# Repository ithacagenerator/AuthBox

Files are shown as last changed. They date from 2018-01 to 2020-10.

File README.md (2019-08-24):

# AuthBox

Some background on where this idea came from in this discussion thread: https://discuss.ithacagenerator.org/t/makerspace-authbox-on-github/565/8

System Diagram

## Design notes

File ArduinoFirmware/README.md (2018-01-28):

***Arduino Libraries***
- https://github.com/Chris--A/Keypad

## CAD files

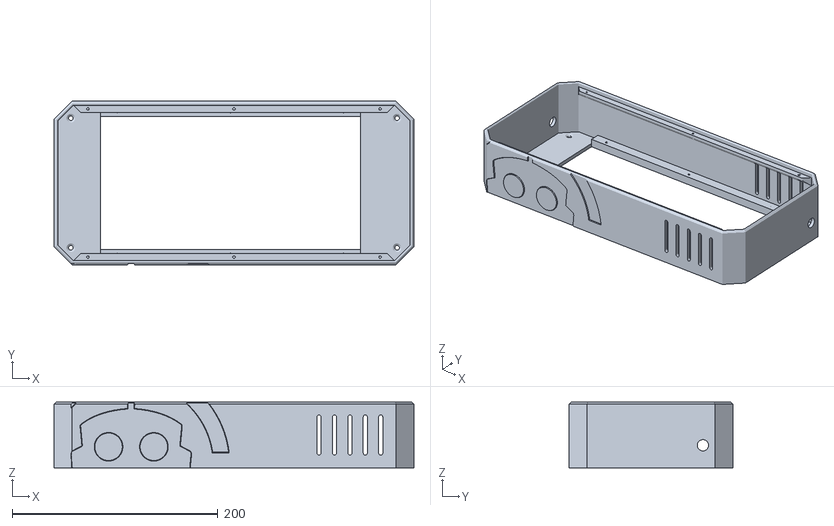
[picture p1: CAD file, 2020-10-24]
Mechanical/authbox_panel.stl
350.0 x 159.0 x 64.0

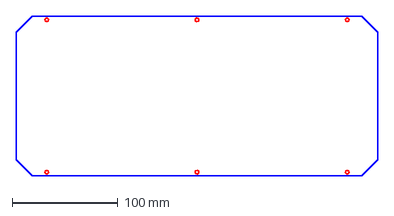
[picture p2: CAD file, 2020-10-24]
Mechanical/top_panel.dxf
341.6 x 150.5 mm

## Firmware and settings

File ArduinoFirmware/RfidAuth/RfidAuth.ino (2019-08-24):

#include <stdlib.h>
#include <stdint.h>
#include <string.h>

// Slight adapatation of Wiegand demo code 
// referenced / linked at http://wiki.seeed.cc/Grove-125KHz_RFID_Reader/
//
// wiring instructions
// RED = 5V from Arduino
// BLACK = GND from Arduino
// WHITE = DIG2 on Arduino
// YELLOW = DIG3 on Arduino
//
// outputs the laser etched code from the RFID reader (sans leading zeroes)
// as an ASCII string, one character at a tim// 
// separated by \r\n 

byte RFIDcardNum[4];
byte evenBit = 0;
byte oddBit = 0;
byte isData0Low = 0;
byte isData1Low = 0;
int recvBitCount = 0;
byte isCardReadOver = 0;

void handleCommands(char c);
uint16_t crc16_update(uint16_t crc, uint8_t a);
uint16_t crc16(char * str, uint8_t len);
uint8_t check_crc16(char * str);
void handleAuthorizeCommand(void);
void handleLockoutCommand(void);
void handleBuzzerOnCommand(void);
void handleBuzzerOffCommand(void);
void enableCounter(void);
void disableCounter(void);

int LOCKOUT_PIN = 13; // Relay control output

// THESE NEED CONFIGURED BASED ON RELAY HARDWARE
int LOCKOUT_PIN_ACTIVE = 1;
int LOCKOUT_PIN_INACTIVE = 1 - LOCKOUT_PIN_ACTIVE;
int INACTIVE_IS_HIGHZ = 1; // means drive Z instead when INACTIVE

int BUZZER_HIGH_PIN = 10;
int BUZZER_LOW_PIN = 9;
boolean buzzer_enabled = false;
boolean buzzer_on = false;
uint32_t previousBuzzerMillis = 0;
const int32_t buzzerInterval = 500; // sets the buzzer beeping frequency

void setup(){
  handleLockoutCommand();
  Serial.begin(9600);
  // Serial.println("Hello RfidAuth");

  attachInterrupt(0, ISRreceiveData0, FALLING );  //data0/tx is connected to pin 2, which results in INT 0
  attachInterrupt(1, ISRreceiveData1, FALLING );  //data1/rx is connected to pin 3, which results in INT 1
  
  pinMode(BUZZER_HIGH_PIN, OUTPUT);
  pinMode(BUZZER_LOW_PIN, OUTPUT);
  digitalWrite(BUZZER_HIGH_PIN, 0); 
  digitalWrite(BUZZER_LOW_PIN, 0);
}

void loop(){
  unsigned long currentMillis = millis();
  if (currentMillis - previousBuzzerMillis >= buzzerInterval) {
    previousBuzzerMillis = currentMillis;

    if(buzzer_enabled){
      if(buzzer_on){
        buzzer_on = false;
        disableCounter();
      }
      else{
        buzzer_on = true;
        enableCounter();        
      }
    }
    else {
      disableCounter();
    }
  }
  
  //read card number bit
  if(isData0Low||isData1Low){
    if(1 == recvBitCount){//even bit
      evenBit = (1-isData0Low)&isData1Low;
    }
    else if( recvBitCount >= 26){//odd bit
      oddBit = (1-isData0Low)&isData1Low;
      isCardReadOver = 1;
      delay(10);
    }
    else{
      //only if isData1Low = 1, card bit could be 1
      RFIDcardNum[2-(recvBitCount-2)/8] |= (isData1Low << (7-(recvBitCount-2)%8));
    }
    //reset data0 and data1
    isData0Low = 0;
    isData1Low = 0;
  }

  if(isCardReadOver){
    if(checkParity()){
      // convert the number to a string
      uint32_t number = *((uint32_t *)RFIDcardNum);
      char tmp[16] = {0};
      sprintf(tmp, "%lu", number);
      uint8_t len = strlen(tmp);
      for(uint8_t ii = 0; ii < len; ii++){
        Serial.println(tmp[ii]);
      }
      Serial.println('#'); // append the 'enter' key
    }
    resetData();
  }

  while (Serial.available()){
      handleCommands(Serial.read());
  }  

}

byte checkParity(){
  int i = 0;
  int evenCount = 0;
  int oddCount = 0;
  for(i = 0; i < 8; i++){
    if(RFIDcardNum[2]&(0x80>>i)){
      evenCount++;
    }
  }
  for(i = 0; i < 4; i++){
    if(RFIDcardNum[1]&(0x80>>i)){
      evenCount++;
    }
  }
  for(i = 4; i < 8; i++){
    if(RFIDcardNum[1]&(0x80>>i)){
      oddCount++;
    }
  }
  for(i = 0; i < 8; i++){
    if(RFIDcardNum[0]&(0x80>>i)){
      oddCount++;
    }
  }
  
  if(evenCount%2 == evenBit && oddCount%2 != oddBit){
    return 1;
  }
  else{
    return 0;
  }
}
void resetData(){
  RFIDcardNum[0] = 0;
  RFIDcardNum[1] = 0;
  RFIDcardNum[2] = 0;
  RFIDcardNum[3] = 0;
  evenBit = 0;
  oddBit = 0;
  recvBitCount = 0;
  isData0Low = 0;
  isData1Low = 0;
  isCardReadOver = 0;
}
// handle interrupt0
void ISRreceiveData0(){
  recvBitCount++;
  isData0Low = 1;
}

// handle interrupt1
void ISRreceiveData1(){
  recvBitCount++;
  isData1Low = 1;
}

uint16_t crc16_update(uint16_t crc, uint8_t a){
    crc ^= a;
    for (uint8_t i = 0; i < 8; ++i){
        if (crc & 1)
            crc = (crc >> 1) ^ 0xA001;
        else
            crc = (crc >> 1);
    }

    return crc;
}

uint16_t crc16(char * str, uint8_t len){
    uint16_t crc = 0;
    for(uint16_t ii = 0; ii < len; ii++){
        crc = crc16_update(crc, str[ii]);
    }
    return crc;
}

uint8_t check_crc16(char * str){
    uint8_t ret = 0;
    uint8_t len = strlen(str);
    if(len >= 5){
        uint16_t calculated_crc16 = crc16(str, len - 4);
        char * temp;        
        uint16_t expected_crc16 = strtol(str + strlen(str) - 4, &temp, 16); // base 16
        if (*temp == NULL){
            if(calculated_crc16 == expected_crc16){
                ret = 1; // success!
            }
        }
    }
    return ret;
}

// state machine for handline incoming characters from the Raspberry Pi
// commands are always terminated by XXXX\n, 
// where XXXX is a CRC16 of the bytes in the command as a HEX-string and \n is a newline character
// CRC16 is computed on the byte values in the line up to the checksum
// CRC16 implementation is explicitly included as a function below
// taking the algorithm from http://www.nongnu.org/avr-libc/user-manual/group__util__crc.html
// this should make it pretty difficult to "accidentally" send an authorization command
// though it's admittedly kind of overkill when the commands are not parametric
// should be relatively easy to extend this command processing logic to support more commands
//
// valid commands are:
//   authorize40A2\n
//   lockoutDF6B\n
//   sirenF012
//   quiet6C9D
void handleCommands(char c){
    static char lineBuffer[64] = {0}; // allow up to 63 characters in a command (plus null terminator)
    static uint8_t idx = 0;
    if(c == '\n' || c == '\r'){
        // newline triggers processing of the command, but only if the checksum is sound
        // remember the last four characters in the buffer are expected to be a hex value string
        if(check_crc16(lineBuffer)){
            lineBuffer[strlen(lineBuffer) - 4] = '\0'; // don't need the checksum anymore
            if(0 == strcmp_P(lineBuffer, PSTR("authorize"))){
                handleAuthorizeCommand();
            }
            else if(0 == strcmp_P(lineBuffer, PSTR("lockout"))){
                handleLockoutCommand();
            }
            else if(0 == strcmp_P(lineBuffer, PSTR("siren"))){
                handleBuzzerOnCommand();
            }
            else if(0 == strcmp_P(lineBuffer, PSTR("quiet"))){
                handleBuzzerOffCommand(); 
            }            
            else {
              Serial.print(F("Unknown Command: \"")); Serial.print(lineBuffer); Serial.print(F("\""));Serial.println();              
            }
        }
        else{
            Serial.print(F("Invalid CRC16: \"")); Serial.print(lineBuffer); Serial.print(F("\""));Serial.println();
        }

        idx = 0; // get ready for next line
        memset(lineBuffer, 0, sizeof(lineBuffer));        
    }
    else{
        // buffer the character
        lineBuffer[idx] = c;

        // advance the write index, the highest value idx should ever hold is
        // 62 for a 64 byte buffer, because 63 must always hold a null terminator
        // if you would overflow, just keep overwriting the last possible buffer entry
        if(idx < (sizeof(lineBuffer) - 1)){
            idx++;
        }
    }
}

void handleAuthorizeCommand(void){    
    Serial.println("authorize");
    pinMode(LOCKOUT_PIN, OUTPUT);
    digitalWrite(LOCKOUT_PIN, LOCKOUT_PIN_ACTIVE);
}

void handleLockoutCommand(void){    
    Serial.println("lockout");   
    if (INACTIVE_IS_HIGHZ) { 
      pinMode(LOCKOUT_PIN, INPUT);
    } else {
      pinMode(LOCKOUT_PIN, OUTPUT);
      digitalWrite(LOCKOUT_PIN, LOCKOUT_PIN_INACTIVE);
    }
}

void handleBuzzerOnCommand(void){
  Serial.println("siren");     
  // set for Phase + Frequency Correct PWM Mode
  // WGM3:0 = 1000
  // IRC1 = TOP   -- determines output frequency = CLK / ( 2 * Prescale * TOP)
  //                 CLK = 16000000 Hz
  //                 Prescale = 1, 8, 64, 256, or 1024
  //                 pick TOP so that output frequency ~ 4000
  // a perfect match is PRESCALER = 8, TOP = 250 ... 16MHz / (2 * 8 * 250) = 1000kHz / 250 = 4kHz
  //
  // COM1A1:0 = 10 set/clear
  // COM1B1:0 = 11 clear/set
  // Set ORC1A = ORCR1B to 1/2 IRCR = 125

  if(!buzzer_enabled){
    OCR1A  = 125;
    OCR1B  = 125;
    ICR1   = 250;
    TCCR1A = _BV(COM1A1) | _BV(COM1B1) | _BV(COM1B0); 
    TCCR1B = _BV(WGM13);  
    buzzer_enabled = true;  
  }
}

void handleBuzzerOffCommand(void){
  Serial.println("quiet");  
  TCCR1A = 0x00;
  TCCR1B = 0x00;
  TCCR1C = 0x00;    
  buzzer_enabled = false;
}

void enableCounter(){
  TCCR1B |= _BV(CS11);
}

void disableCounter(){
  TCCR1B &= ~_BV(CS11);
}

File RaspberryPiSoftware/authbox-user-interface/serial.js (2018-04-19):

/* jshint esversion:6 */
/* jshint node: true */

const util = require('./util');
const promiseDoWhilst = require('promise-do-whilst');
const moment = require('moment');
const SerialPort = require('serialport');

module.exports = (function() {
  console.log('Initialized Serial');

  let inputHandler = null;
  let discoveredArduinos = [];

  // handler should be a function that receives a line of data
  function setInputHandler(handler) {
    inputHandler = handler;
  }

  function authorize() {    
    // broadcast to all attached arduinos
    return Promise.all(discoveredArduinos.map(p => sendCommandExpectResponse(p, 'authorize', 'authorize', 100)));    
  }

  function deauthorize() {
    // broadcast to all attached arduinos
    return Promise.all(discoveredArduinos.map(p => sendCommandExpectResponse(p, 'lockout', 'lockout', 100))); 
  }

  function buzzeron(){
    // broadcast to all attached arduinos
    return Promise.all(discoveredArduinos.map(p => sendCommandExpectResponse(p, 'siren', 'siren', 100)));    
  }

  function buzzeroff(){
    // broadcast to all attached arduinos
    return Promise.all(discoveredArduinos.map(p => sendCommandExpectResponse(p, 'quiet', 'quiet', 100))); 
  }

  function listPorts(manufacturerRegex){    
    return SerialPort.list()
    .then((availablePorts) => {    
      discoveredArduinos =  availablePorts.filter(p => !manufacturerRegex || 
        (p.manufacturer && manufacturerRegex.test(p.manufacturer)));
      return discoveredArduinos;
    })
    .catch((error) => {
      console.error(error);
    });
  }

  // arduino is an object result of SerialPort.list
  // commandToSend is any string
  // responseToExpect is a [optional] regular expression that should be seen by the data
  //   handler for this arduino [optionally] within within_ms before an exeception is thrown
  // if you don't expect / care about a response, call it without responseToExpect or within_ms
  // if you want to wait up to _forever_ for a response, call it without within_ms
  function sendCommandExpectResponse(arduino, commandToSend, responseToExpect = null, within_ms = -1){
    // first you have to calculate the crc16 of the commandToSend string
    // and tack it onto the end as a hex-string and a newline
    if (responseToExpect){ arduino.waitingForResponseData = true; }
    return new Promise(function(resolve, reject){
      const extended_command = `${commandToSend}${util.crc16(commandToSend)}\n`;      
      arduino.handle.write(extended_command, function(err){
        if(err){ 
          console.err(err);
          reject(err); 
        } else { 
          resolve(); 
        }
      });
    })
    .then(function(){
      const startExpectingResponse = moment();
      if(responseToExpect){
        return promiseDoWhilst(util.delayPromise(10), 
        function(){
          if(arduino.response === responseToExpect){
            return false; // we're done because got expected response
          } else if(within_ms > 0) {
            const now = moment();
            const diff = now.diff(startExpectingResponse, 'ms');
            if(diff > within_ms){
              return false; // we're done because timeout,              
            }
          } 
          
          return true; // haven't returned false, so we're not done waiting yet
        });
      }
    })
    .then(() => {
      if (responseToExpect){ arduino.waitingForResponseData = false; }
      arduino.response = '';
    })
    .catch(function(error){
      if (responseToExpect){ arduino.waitingForResponseData = false; }
      arduino.response = '';
      console.error(error);
    });
  }

  // port is a single element from the listPorts results    
  function establishConnection(port){
    // must return a promise
    port.handle = new SerialPort(port.comName, { baudRate: 9600 }); 
    port.response = ''; // place holder for buffering protocol response data
    let parser = port.handle.pipe(new SerialPort.parsers.Regex({ regex: /[\r\n]+/ }));    
    parser.on('data', function(data){

      // console.log(data);
         
      if(data.length === 0){
        return;
      }      
      
      if (port.waitingForResponseData && ['0','1','2','3','4','5','6','7','8','9','#'].indexOf(data) < 0){
        port.response = port.response ? `${port.response}${data}` : `${data}`;
      } else {
        if(inputHandler){
          inputHandler(data);        
        } else {
          console.log('Data received before inputHandler registered', [data.toString()]);
        }
      }
    });
    
    return new Promise(function(resolve, reject){
      port.handle.on('open', resolve);
    })
    .then(() => {
      console.log(`opened ${port.comName} successfully`);
    })
    .catch((error) => {
      console.error(`error opening ${port.comName}`, error);
    });
  }

  function connectToPorts(ports){        
    let promises = ports.map(p => establishConnection(p));
    return Promise.all(promises);
  }

  function begin() {
    return listPorts(/arduino/i)
    .then(connectToPorts);
  }

  return {
    setInputHandler,
    authorize,
    deauthorize,
    buzzeron, 
    buzzeroff,
    begin
  };
})();

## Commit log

2018-01-28 add initial sketch for Arduino (currently empty)
2018-01-28 first crack at arduino sketch to accept commands from pi and report keypresses to to pi, not bound to pins yet
    [KeypadAuth.ino]
2018-01-29 add v1 mount point for api calls
2018-02-05 insert, not update, is called for on authorize
2018-02-08 added some angular2 material action
2018-02-08 angular material updates, add a form field for management password
2018-02-08 add class to body per angular material2 theming guidelines https://material.angular.io/guide/theming
2018-02-12 deletion works now and there's a button to navigate to the authbox detail page
2018-02-17 apply filter to query results
2018-02-17 case insenitive
2018-02-17 make new data get fetched from the server when the filter text changes
2018-02-17 print the count out
2018-02-19 add boxname to authorization record to ease filtering later
2018-02-19 filter on box_name
2018-02-19 finished implementing member history and some small style tweaks for button section in dialogs
2018-02-23 initial modules for raspberry pi firmware
2018-03-02 list ports finds attached arduinos
2018-03-02 factored out a util module, implemented listing ports and implementing serial listing and attaching, added more mocks to avoid runtime errors, and made some adjustments to code entry handling
    [serial.js]
2018-03-03 add pbkdf2 and homedir packages to raspberry pi software
2018-03-10 added buzzer support to arduino both firmwares
    [KeypadAuth.ino, RfidAuth.ino]
2018-03-10 add commands and integration for buzzer behavior into raspberry pi software
    [serial.js]
2018-03-11 float the csv buttons right
2018-03-23 fixed bug related to interaction between buzzeroff command and rfid reader
    [serial.js]
2018-04-19 do not reset buzzer on vacuous buzzeron commands
    [KeypadAuth.ino]
2018-10-03 taking another crack at this raspberry pi software
2018-10-17 move the FAB buttons to the lower left (instead of the lower right)
2018-10-24 add date filtering
2019-08-24 add build and load files for rfid using arduino cli
2019-08-24 commit changes from raspberry pi
2019-09-21 making a base-mounting plate for the modules
    [authbox-plate.scad, cyl_head_bolt-drawAllScript.scad, cyl_head_bolt.scad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]
2019-09-21 added PSU
    [authbox-plate.scad]
2019-09-21 added mount for RFID reader
    [authbox-plate.scad]
2019-09-21 add arduino
    [authbox-plate.scad]
2019-09-21 add relay module
    [authbox-plate.scad]
2019-09-21 addred terminal blocks
    [authbox-plate.scad]
2019-09-22 minor adjustments
    [authbox-plate.scad]
2019-09-24 organized the components in 2D space
    [authbox-plate.scad]
2019-09-29 fix power supply interior hole positions
    [authbox-plate.scad]
2020-01-19 Bump sshpk in /RaspberryPiSoftware/authbox-user-interface
    Bumps [sshpk](https://github.com/joyent/node-sshpk) from 1.13.1 to 1.16.1.
    - [Release notes](https://github.com/joyent/node-sshpk/releases)
    - [Commits](https://github.com/joyent/node-sshpk/compare/v1.13.1...v1.16.1)
2020-01-19 Bump set-value in /RaspberryPiSoftware/authbox-user-interface
    Bumps [set-value](https://github.com/jonschlinkert/set-value) from 2.0.0 to 2.0.1.
    - [Release notes](https://github.com/jonschlinkert/set-value/releases)
    - [Commits](https://github.com/jonschlinkert/set-value/compare/2.0.0...2.0.1)
2020-01-19 Bump stringstream in /RaspberryPiSoftware/authbox-user-interface
    Bumps [stringstream](https://github.com/mhart/StringStream) from 0.0.5 to 0.0.6.
    - [Release notes](https://github.com/mhart/StringStream/releases)
    - [Commits](https://github.com/mhart/StringStream/compare/v0.0.5...v0.0.6)
2020-01-19 Bump tar-fs in /RaspberryPiSoftware/authbox-user-interface
    Bumps [tar-fs](https://github.com/mafintosh/tar-fs) from 1.16.0 to 1.16.3.
    - [Release notes](https://github.com/mafintosh/tar-fs/releases)
    - [Commits](https://github.com/mafintosh/tar-fs/compare/v1.16.0...v1.16.3)
2020-01-19 Bump lodash in /RaspberryPiSoftware/authbox-user-interface
    Bumps [lodash](https://github.com/lodash/lodash) from 4.17.5 to 4.17.15.
    - [Release notes](https://github.com/lodash/lodash/releases)
    - [Commits](https://github.com/lodash/lodash/compare/4.17.5...4.17.15)
2020-01-19 Bump extend in /RaspberryPiSoftware/authbox-user-interface
    Bumps [extend](https://github.com/justmoon/node-extend) from 3.0.1 to 3.0.2.
    - [Release notes](https://github.com/justmoon/node-extend/releases)
    - [Changelog](https://github.com/justmoon/node-extend/blob/master/CHANGELOG.md)
    - [Commits](https://github.com/justmoon/node-extend/compare/v3.0.1...v3.0.2)
2020-01-19 add base href to build
    [authbox-plate.stl]
2020-02-20 bring along members into the current month
2020-02-22 don't fet eots becauset hey are too broad
2020-03-07 print amounts
2020-03-15 add case logic to better comprehend cancellations
2020-07-01 Added new mechanical enclosure models
    [authbox-plate.scad, authbox-plate.stl, authbox_enclosure.stl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]
